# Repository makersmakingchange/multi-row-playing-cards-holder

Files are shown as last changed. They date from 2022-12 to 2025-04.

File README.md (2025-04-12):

<!---  Open Source Assistive Technology: GitHub Readme Template  --->
<!---  TITLE Should match the name of the GitHub repository. Choose something descriptive rather than whimsical.   --->
 # Multi Row Playing Cards Holder

<!---  SUMMARY A brief summary of the project. What it does, who it is for, how much it costs.  --->
The Multi Row Playing Cards Holder is an assistive device for holding playing cards. This fully 3D-printed device aims to assist those with limited hand dexterity by giving them an alternate means of holding their playing cards. Users will be able to place their cards into the tabletop holder which will discreetly display their cards during gameplay.

This design was created by [Dave Jones](https://www.thingiverse.com/djones1t/designs) and posted on [Printables.com](https://www.thingiverse.com/thing:2863434).

<!---  PHOTO  --->
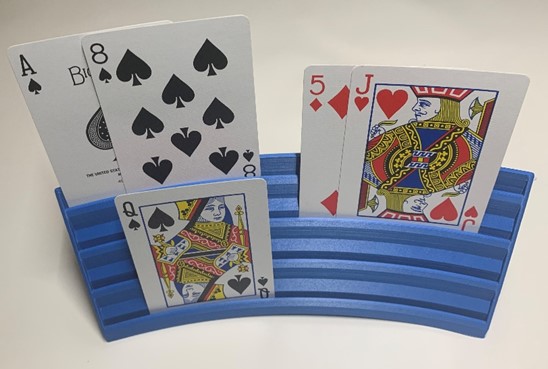
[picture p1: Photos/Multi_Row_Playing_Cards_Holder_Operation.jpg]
A blue 3D printed multi row playing cards holder displaying various cards.


## Makers Making Change Assistive Device Library
 - https://www.makersmakingchange.com/s/product/multi-row-playing-cards-holder/01tJR000000690mYAA

## How to Obtain a Multi Row Playing Cards Holder
### 1. Do it Yourself (DIY) or Do it Together (DIT)

This is an open-source assistive technology, so anyone is free to build it. All of the files and instructions required to build the Multi Row Playing Cards Holder are contained within this repository. Refer to the Maker Checklist below.

### 2. Request a build of this device

If you would like to obtain a Multi Row Playing Cards Holder , you may submit a build request through the [MMC Library Page](https://makersmakingchange.com/project/multi-row-playing-cards-holder/). The requestor is responsible for the cost of materials and any shipping.

### 3. How to build this device for someone else

If you have the skills and equipment to build this device, and would like to donate your time to create the switch for someone who needs it, visit the [MMC Maker Wanted](https://makersmakingchange.com/maker-wanted/) section.

## Getting Started

### 1. Read the Makers Checklist

The Makers Checklist contains a list of tasks to complete to build the device.

### 2. Print the 3D Printable component

The print files can be in the [/Build_Files/3D_Printing_Files](/Build_Files/3D_Printing_Files/) folder.

## Files
<!--- FILES This section includes all the information and files required to build and modify the device, including documentation, design files, and build files. --->

### Documentation
<!--- DOCUMENTATION --->
| Document | Version | Link |
|---|---|---|
| Design Rationale | 1.0 | [Multi_Row_Playing_Cards_Holder_Design_Rationale](/Documentation/Multi_Row_Playing_Cards_Holder_Design_Rationale.pdf) |
| Maker Checklist | 1.0 | [Multi_Row_Playing_Cards_Holder_Maker_Checklist](/Documentation/Multi_Row_Playing_Cards_Holder_Maker_Checklist.pdf) |
| Bill of Materials | 1.0 | [Multi_Row_Playing_Cards_Holder_BOM](/Documentation/Multi_Row_Playing_Cards_Holder_BOM.xlsx) |
| 3D Printing Guide | 1.0 | [Multi_Row_Playing_Cards_3D_Printing_Guide](/Documentation/Multi_Row_Playing_Cards_Holder_3D_Printing_Guide.pdf) |
| Assembly Guide | n/a | No Assembly Required |
| User Guide | 1.0 | [Multi_Row_Playing_Cards_Holder_User_Guide](/Documentation/Multi_Row_Playing_Cards_Holder_User_Guide.pdf) |
| Changelog | 1.0 | [Multi_Row_Playing_Cards_Holder_Changelog](/Documentation/Multi_Row_Playing_Cards_Holder_Changelog.pdf) |

### Design Files
<!-- DESIGN FILES -->
<!-- If possible, include a copy of original design files to facilitate easy editing and customization. --->
 - Not available.

### Build Files
<!-- BUILD FILES -->
 - [3D Printing Files](/Build_Files/3D_Printing_Files)

## Attribution
<!-- ATTRIBUTION -->
<!-- Include any information related to the development of the design. This may include who identified the initial challenge, who contributed to the design --->
 - Design: [Dave Jones](https://www.thingiverse.com/djones1t/designs)
 - Documentation by Neil Squire / Makers Making Change.

## License
<!--- LICENSE --> 
<!-- Choose an appropriate license. We recommend an open-source hardware compatible license. --->
The design of the [Multi Row Playing Cards Holder](https://www.thingiverse.com/thing:2863434) by Dave Jones is licensed under [Creative Commons (International License) Public Domain](http://creativecommons.org/publicdomain/zero/1.0/).

Accompanying material such as instruction manuals, videos, and other copyrightable works that are useful but not necessary to design, make, test, or prepare the Multi Row Playing Cards Holder are published under a Creative Commons Attribution-ShareAlike 4.0 license <https://creativecommons.org/licenses/by-sa/4.0/> (CC BY-SA 4.0).

----

<!-- ABOUT MMC START -->
## About Makers Making Change
[Makers Making Change Logo](https://www.makersmakingchange.com/)

Makers Making Change is a program of [Neil Squire](https://www.neilsquire.ca/), a Canadian non-profit that uses technology, knowledge, and passion to empower people with disabilities.

Makers Making Change leverages the capacity of community based Makers, Disability Professionals and Volunteers to develop and deliver affordable Open Source Assistive Technologies.

 - Website: [www.MakersMakingChange.com](https://www.makersmakingchange.com/)
 - GitHub: [makersmakingchange](https://github.com/makersmakingchange)
 - Bluesky: [@makersmakingchange.bsky.social](https://bsky.app/profile/makersmakingchange.bsky.social)
 - Instagram: [@makersmakingchange](https://www.instagram.com/makersmakingchange)
 - Facebook: [makersmakechange](https://www.facebook.com/makersmakechange)
 - LinkedIn: [Neil Squire Society](https://www.linkedin.com/company/neil-squire-society/)
 - Thingiverse: [makersmakingchange](https://www.thingiverse.com/makersmakingchange/about)
 - Printables: [MakersMakingChange](https://www.printables.com/@MakersMakingChange)

### Contact Us
For technical questions, to get involved, or to share your experience we encourage you to [visit our website](https://www.makersmakingchange.com/) or [contact us](https://www.makersmakingchange.com/s/contact).
<!-- ABOUT MMC END -->

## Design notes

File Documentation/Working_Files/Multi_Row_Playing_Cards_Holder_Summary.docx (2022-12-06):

# Title

Multi Row Playing Cards Holder

## Subtitle

<Short description>

## Device Specifications

Build Time:

< 1hr

1-4 hr

5-10hr

>10hr

Cost:

$0 - $10

$11 - $25

$26 - $50

$51 - $100

$101 - $250

$250+

Stage:

Skills:

Need:

Disability:

Difficulty:

License:

Usages:

Type:

Designer:

## Device Details

### Overview

The Multi-Row Playing Cards Holder is an assistive device for holding playing cards. This fully 3D-printed device aims to assist those with limited hand dexterity by giving them an alternate means of holding their playing cards. Users will be able to place their cards into the tabletop holder which will discreetly display their cards during gameplay.

Original device listing on printables.com: Thing files for Full Size Playing Card Holder by Djones1t – Thingiverse (https://www.thingiverse.com/thing:2863434/files)

### Usage

This device is intended to be used with standard sized playing cards. Larger cards can be used but will decrease the maximum number of cards that can be held. Cards can be placed among its four rows to be displayed.

### Cost

Approximately $1.60 CAD for filament.

### Build Instructions

The Multi Row Playing Cards Holder consists of a single 3D printed component. Refer to the Maker Guide and 3D Print guide for detailed instructions.

#### Skills Required

- 3D Printing

#### Time Required

- 3D Printing Time: 10h 26m
- Assembly Time: None

### 3D Printing

- 1X Multi-Row Playing Cards Holder

### Attribution

Design: Dave Jones (https://www.thingiverse.com/djones1t/designs) licensed under Creative Commons (International License) Public Domain (https://creativecommons.org/licenses/by/4.0/).

Documentation: Neil Squire / Makers Making Change

© 2022 by Neil Squire. This work is licensed under the CC BY SA 4.0 License: http://creativecommons.org/licenses/by-sa/4.0 Files available at https://makersmakingchange.com/project/playing-cards-holder Page 1 of 2

V1.0 | November 2022 Playing Cards Holder Summary

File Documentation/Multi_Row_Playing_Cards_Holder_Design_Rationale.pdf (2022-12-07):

V1.0 | October 2022

## Playing Cards Holder

## DESIGN RATIONALE

© 2022 by Neil Squire. (https://neilsquire.ca/)

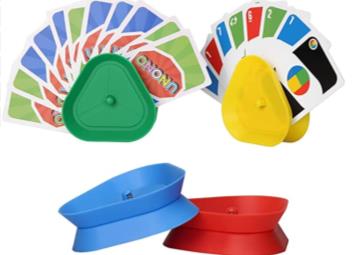
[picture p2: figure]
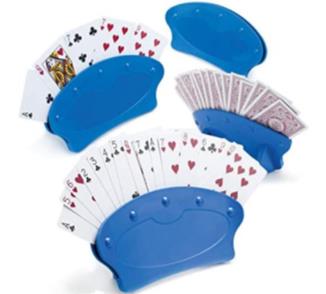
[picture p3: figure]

This work is licensed under the CC BY SA 4.0 License: http://creativecommons.org/licenses/by-sa/4.0
Files available at https://makersmakingchange.com/project/multi-row-playing-cards-holder | Page 1 of 7

### Introduction

The Playing Cards Holder is an assistive device for holding playing cards. This fully 3D printed device aims to assist those with limited dexterity by giving them an alternate means for holding their playing cards. Users will be able to place their cards into the holder to have them displayed during game play.

### Research

### Handheld Holders

There are a variety of commercially available card holders that assist in holding cards within a person’s hand. This type sandwiches cards between its two halves and holds them secure with friction. They cost approximately $20 and are targeted to aid users with arthritis.

Brybelly Triangle Shaped Hands-Free Playing Card Holder : Amazon.ca: Toys & Games (https://www.amazon.ca/Brybelly-Triangle-Shaped-Hands-Free-Playing/dp/B00DQRDK6K?hvadid=80470598951881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)

### Tabletop Holders

The other common type is the tabletop holder. This allows cards to be held hands free but requires a table or surface to be placed on. They cost around $25 for a set and are targeted to aid users with arthritis.

Playing Card Holder Tray Great for Seniors & Kids Hands Free Playing Card Holders (Set of 4), Standard Playing Card Decks - Amazon Canada (https://www.amazon.ca/Playing-Holder-Great-Seniors-Holders/dp/B07BHRRJ9K?hvadid=80470598951881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)

## DESIGN RATIONALE

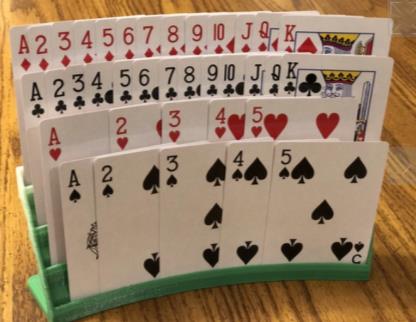
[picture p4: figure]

Files available at https://makersmakingchange.com/project/multi-row-playing-cards-holder | Page 2 of 7

### Requirements

### Goals

G01 | Make it easier for users with limited dexterity hold playing cards
G02 | Assist recreation and leisure

### Functional Requirements

F01 | Cards should be kept hidden from other players
F02 | Cards should still be accessible when holder is full
F03 | Holder must be stable enough to not tip over
F04 | Must be easy to place and take cards from holder
| (How many cards should it hold?)

### Non-functional Requirement

NF01 | Should be easy to clean
NF02 | Capable of holding various sized cards

### Constraints

C01 Must be printable on standard sized 3D printers

### Existing Designs

Feedback was gathered from users with various degrees of hand dexterity challenges.

### Multi-Tier Card Holder - User Test 1

This design allows for four rows of cards to be held with a slight curve. This offers enough room to hold an entire standard deck of cards: one full suit (13) per row. However, it did not encompass the required user accessibility. Users found it too difficult to access and place cards among the multiple crowded rows. Singles tiered card holders will be the ideal approach.

Source: Full Size Playing Card Holder by Djones1t - Thingiverse (https://www.thingiverse.com/thing:2863434)

## DESIGN RATIONALE

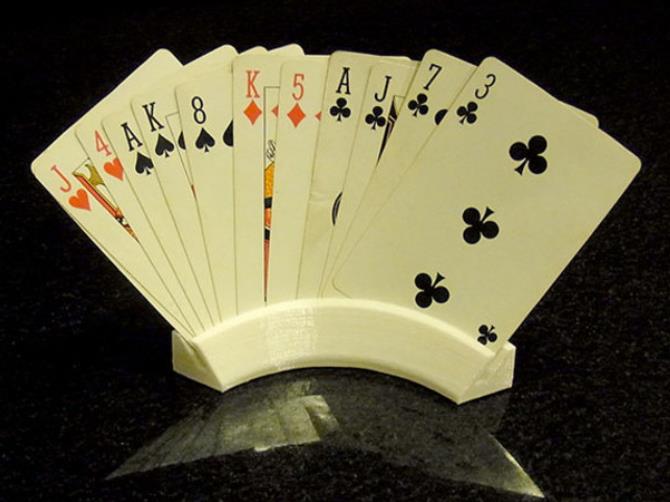
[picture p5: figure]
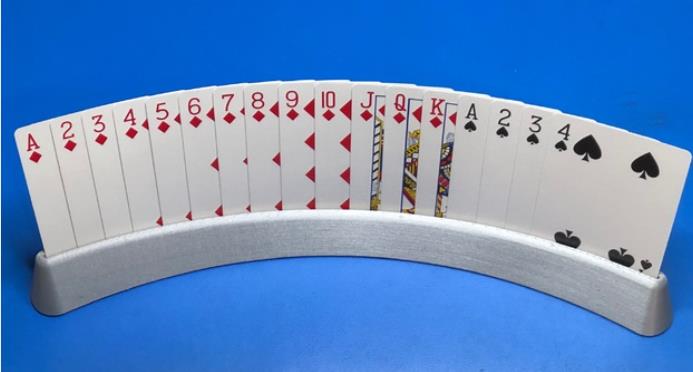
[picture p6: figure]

Files available at https://makersmakingchange.com/project/multi-row-playing-cards-holder | Page 3 of 7

Licence: Creative Commons — Attribution 4.0 International — CC BY 4.0 (https://creativecommons.org/licenses/by/4.0/legalcode)

### Single Tier Card Holder - User Test 2

This single layer card holder curves to angle the cards towards the users and holds the cards in a tilted back position. After testing, users found the single layer to be ideal for their accessible needs but found this design too small. The holder became too crowded when loaded up with cards.

Source: Playing Card Holder - Holds your cards for you while you play! by muzz64 - Thingiverse (https://www.thingiverse.com/thing:781900)

Licence: Creative Commons — Attribution 4.0 International — CC BY 4.0 (https://creativecommons.org/licenses/by/4.0/legalcode)

### Other Design Considerations

### Holder 1 – Extra Wide Playing Card Holder

- Designed to be the maximum size for the Prusa MK3
- Must be scaled to 85% to fit on Ender3 bed
- Functionality decreased due to scaling: card slot quite narrow
- 5h 36m print time
- Single tier
- Curved slightly towards user
- Holds cards slightly tilted back
- Holds 4 non-over lapping cards and approximately a maximum of 18 spaced closely

## DESIGN RATIONALE

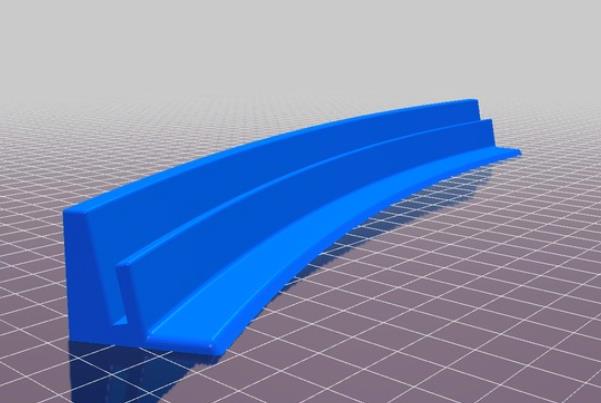
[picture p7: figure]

Files available at https://makersmakingchange.com/project/multi-row-playing-cards-holder | Page 4 of 7

Source: Thing files for Extra Wide Playing Card Holder by abelsm2 - Thingiverse (https://www.thingiverse.com/thing:3417179/files)

Licence: Creative Commons (https://creativecommons.org/licenses/by-nc-sa/4.0/legalcode)

### Holder 2 – Playing Card Holder

- Must be scaled to 90% to fit on Ender3 bed
- Functionally still works great while scaled
- 5h 41m print time
- Single tier
- Curved slightly towards user
- Holds cards slightly tilted back
- Wider base for stability
- Holds 4 non-over lapping cards and approximately a maximum of 20 spaced closely
- Interesting design with the rear wall being taller than the from allowing cards to be ‘banked’ in

Notes: This would be a good design to get user feedback on. It has the highest card capacity of the single tier holders considered. Its wide base makes it very stable and almost hard to tip over. It would also be interesting to see if users find this cross section more accessible.

Source: Thing files for Playing Card Holder by skartz - Thingiverse (https://www.thingiverse.com/thing:2745725/files)
Licence: Creative Commons (https://creativecommons.org/licenses/by-nc-sa/4.0/legalcode)

### Holder 3 – Playing Cards Holder

- Sized perfectly for Prusa Mini (will fit on all maker printers)
- 4h 17m print time
- Single tier
- Slight curve
- Holds cards straight up (no lean)
- Circular feet for stability
- Holds 3 non-over lapping cards and approximately a maximum of 14 spaced closely

## DESIGN RATIONALE

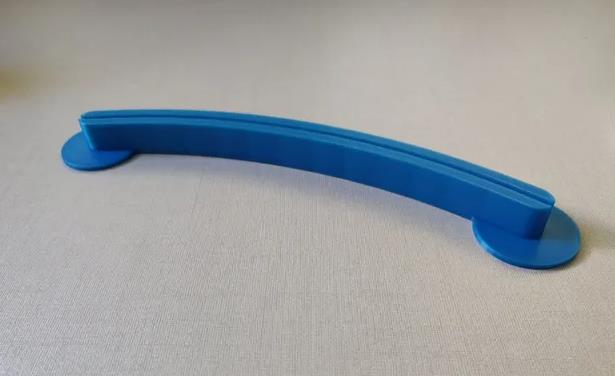
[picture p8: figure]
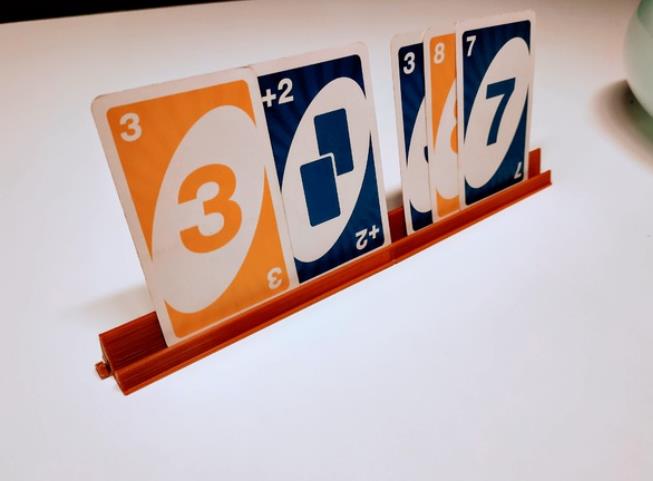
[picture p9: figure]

Files available at https://makersmakingchange.com/project/multi-row-playing-cards-holder | Page 5 of 7

Notes: User feedback on this design could be beneficial. Its print size is convenient for maker printers and the design of its base makes it very stable. More information on whether this meets user accessibility would be needed.

Source: Playing Cards Holder by DrorFux | Download free STL model | Printables.com (https://www.printables.com/model/175640-playing-cards-holder)
Licence: Creative Commons (https://creativecommons.org/licenses/by-nc-sa/4.0/legalcode)

### Holder 4 – Connectable Playing Cards Holder

- Modular design allowing for multiple units to connect together
- Individual components will fit on any printer
- 1h 48m print time
- No curve
- Holds cards slightly tilted back
- Similar cross section as holder 2
- Smaller size: 12cm long and 2 cm wide
- Tab to attach multiple together is quite weak

Notes: Due to its narrow base and lack of curve, this design was quite unstable. However, it was the only modular single tier card holder I could find. If a custom holder is to be designed, this could be a good foundation to expand from.

Source: Thing files for Card holder for playing cards by elliotsfar - Thingiverse (https://www.thingiverse.com/thing:4248953/files)

## DESIGN RATIONALE

Files available at https://makersmakingchange.com/project/multi-row-playing-cards-holder | Page 6 of 7

Licence: Creative Commons (https://creativecommons.org/licenses/by-nc-sa/4.0/legalcode)

### Existing Design Comparison

| Design 1 | Design 2 | Design 3 | Design 4 | User Test 1
Style (handheld / desk) | Desk | Desk | Desk | Desk | Desk
Size [cm] | ~27 x 2.2 x 2 | ~25 x 2.2 x 2.7 | ~21 x 1.7 x 1.1 | ~12 x 1.6 x 2 | ~20.5 x 7.5 x 4
Print Time | 5h 36m | 5h 41m | 4h 17m | 1h 48m | 10h 26m
Cost | ~$1.00 | ~$1.05 | ~$0.85 | ~$0.33 | 64g
License | Creative Commons | Creative Commons | Creative Commons | Creative Commons | Creative Commons (https://creativecommons.org/licenses/by-nc-sa/4.0/legalcode)

### User Feedback

Holder 1, Holder 2, and the User test 1 card holders were sent for user feedback. The following are some of their responses.

### What challenges will this device help overcome?

- Arthritis, limited dexterity, etc. post CVA, brain injury, cognitive decline, chronic pain, fine and gross motor limitations, decreased strength/endurance, arthritis, post surgery (shoulder, wrist, etc.), paralysis, MS, Guillain Barre Syndrome, CP, ALS, Parkinson’s/tremors,

### How will this device be used?

- Handheld? A fan shape would be better for handheld
- At a desk or a table? Yes
- Used with one hand? One or two, depending on the person

### What style of holder works best?

- Multiple rows? Depending on game, multiple row would be best. Better to have too much room rather than not enough.
- Single row?

How many cards should this holder hold? Games like bridge deal 13 cards, cribbage deals 6 cards

## DESIGN RATIONALE

Files available at https://makersmakingchange.com/project/multi-row-playing-cards-holder | Page 7 of 7

### Additional Comments

- Is there an handheld option? It should be thicker to hold onto or have an option to attach to a tray on a wheelchair perhaps or have a hand strap.
- could suction cups or something similar be added to the table top version so that it doesn’t slide around when clients are removing a card?

### Detailed Design

After receiving user feedback, the optimal design for the paying cards holder is either User Test 1 or Holder 2. The first is a multi-tier holder capable of holding many cards. It has approximate dimensions of 20.5 x 7.5 x 4 cm. The initial impression of this holder was that it may become too difficult to use once full of cards. However, after further testing from users, the fact that it can hold over twice the number of cards makes it a better option when used below max capacity.

The second holder is the largest single tier holder considered but may still be limiting based on the maximum number of cards it can hold. It has approximate dimensions of 25 x 2.2 x 2.7 cm. This is a good option based on its wide base and cross section design.

Both designs are maker friendly, sturdy, and accessible. Therefore, both designs will be released as separate devices.

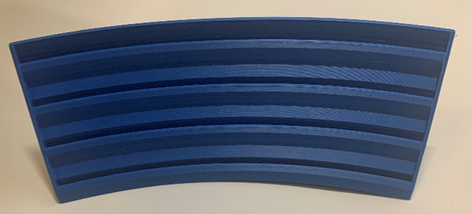
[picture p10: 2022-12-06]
Photos/Multi Row Playing Cards Holder Front.png

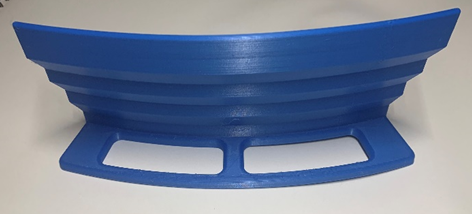
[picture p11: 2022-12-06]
Photos/Multi Row Playing Cards Holder Back.png

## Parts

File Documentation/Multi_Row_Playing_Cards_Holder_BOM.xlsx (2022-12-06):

Device: Multi Row Playing Cards Holder |  | Total Cost | Total Print time (hr) | Total filament (g)
Version: V1.0 | Date Created: 11/23/2022 | $1.60 | 10.43 | 64
Commercial Parts:
Part type (Electrical. Mechanical, Sanitization, ect) | Part Name | Quantity Needed | Pkg Quantity | Price per package | Price per Unit | Price for qty needed | Link
No commercial parts needed
3D Printed Parts ESTIMATED PRICING USING 1KG ROLL COST: | $25.00
Part | Description | Quantity Needed | TOTAL Mass (g) | Estimated Price | Print Time (Min) | Link
Full Sized Playing Cards Holder | Multi-Tier Holder | 1 | 64 | $1.60 | 626 | Thing files for Full Size Playing Card Holder by Djones1t - Thingiverse (https://www.thingiverse.com/thing:2863434/files)
 |  |  |  | $0.00
 |  |  |  | $0.00
 |  |  |  | $0.00
 |  |  |  | $0.00
 |  |  | Total Print Cost: | $1.60
Tools for Assembly
No tools needed
Alternatives (if there are other sources for some parts link them below)
Part and description

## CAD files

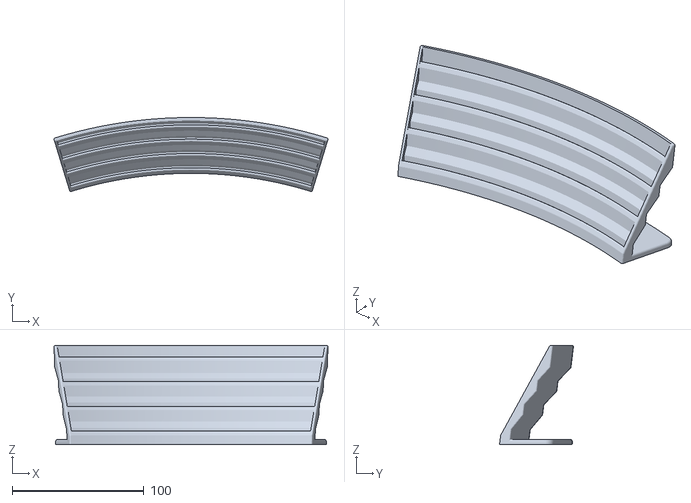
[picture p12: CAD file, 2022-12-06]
Build_Files/3D_Printing_Files/holder-4row.stl
208.2 x 56.2 x 75.5

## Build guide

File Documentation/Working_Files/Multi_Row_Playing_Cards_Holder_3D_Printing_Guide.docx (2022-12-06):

# 3D Printing Summary

Metrics | 4 Row Playing Cards Holder
Total Print Time (min) | 626
Total Number of Components | 1
Typical Total Mass (g) | 64
Typical Number of Print Setups | 1

# 3D Printing Settings

Print File Name | Qty | Total Print Time (hr:min) | Mass (g) | Infill (%) | Support(Y/N) | Layer Height/ Nozzle Diameter(mm) | Notes (orientation, special settings, etc.)
Holder-4row.stl | 1 | 10:26 | 30 | 15 | N | 0.2/0.4 | -Rotate to fit on print bed -Do not scale

# Customization Options

Users may request their choice of print colour.

# Post-Processing

No post-processing is required as this part does not require any supports. Rather inspect the print to ensure that all edges and surfaces are smooth.

# Examples of Quality Prints

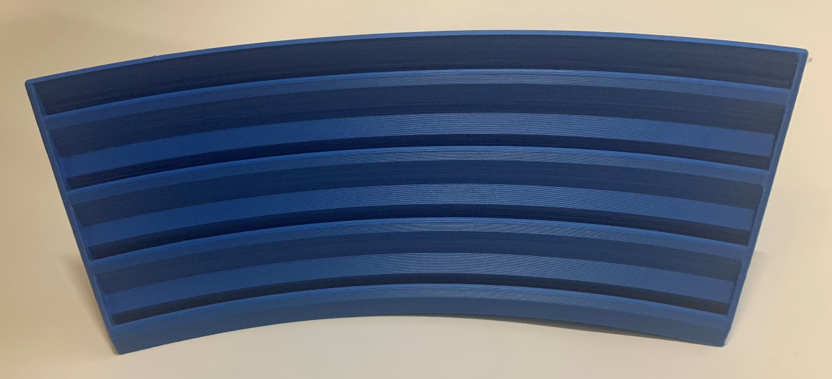
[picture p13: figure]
A blue 3D printed playing cards holder with 4 rows to hold cards.

© 2022 by Neil Squire. This work is licensed under the CC BY SA 4.0 License: http://creativecommons.org/licenses/by-sa/4.0 Files available at https://makersmakingchange.com/project/multi-row-playing-cards-holder Page 1 of 2

V1.0 | November 2022 Multi Row Playing Cards Holder 3D Printing Guide

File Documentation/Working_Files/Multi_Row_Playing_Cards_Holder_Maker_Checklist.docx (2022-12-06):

# Maker To Do List

- Read through the Print Guide to become familiar with print orientation and settings
- Talk to User about customization options (e.g., colour)
- Print the device
- Test the device
- Print “User Quick Guide”

# Items to Give to User

- Multi Row Playing Cards Holder
- “User Quick Guide”

© 2022 by Neil Squire. This work is licensed under the CC BY SA 4.0 License: http://creativecommons.org/licenses/by-sa/4.0 Files available at https://makersmakingchange.com/project/multi-row-playing-cards-holder Page 1 of 1

V1.0 | November 2022 Multi Row Playing Cards Holder Maker Checklist

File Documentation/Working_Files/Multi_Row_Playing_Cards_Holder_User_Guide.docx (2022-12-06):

## Introduction

The Multi Row Playing Cards Holder is an assistive device for holding playing cards. This fully 3D-printed device aims to assist those with limited hand dexterity by giving them an alternate means of holding their playing cards. Users can place their cards into the tabletop holder which will discreetly display their cards during gameplay.

## Features

This device has 4 rows of slots for holding playing card and on the back side is a handle to carry it from.

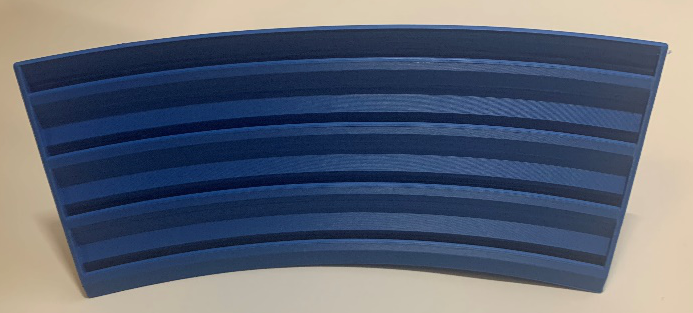
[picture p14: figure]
The front side of a blue 3D printed playing cards holder with 4 rows to display cards.
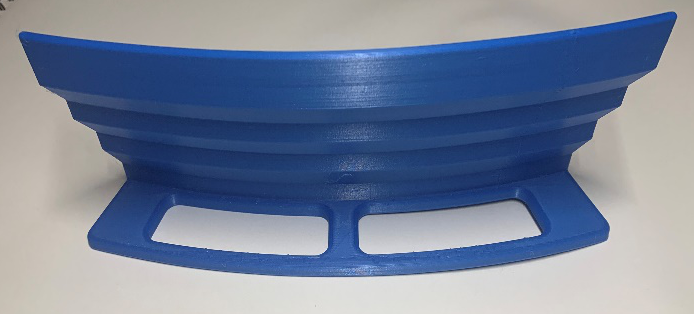
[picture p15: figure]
The back side of a blue 3D printed playing cards holder showing that the base also acts as a handle to carry it from.

## Usage

Place the Playing Cards Holder on a flat surface and face it away from other players. Cards can then be place among the four rows to be displayed during game play.

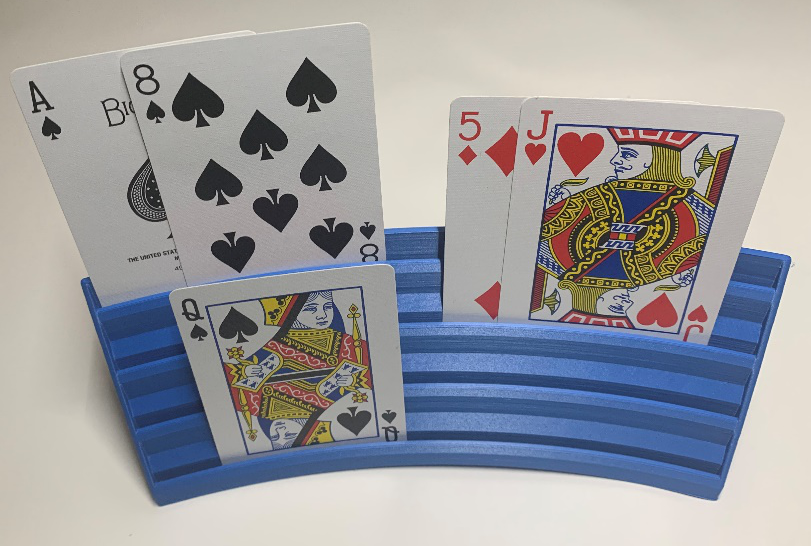
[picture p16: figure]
A blue 3D printed playing cards holder displaying various cards.

## Compatibility

This cards holder is intended to be used with standard sized playing cards. Larger cards can be used but will decrease the maximum number of cards that can be displayed.

## Specifications

Dimensions (mm) | | | | | | Mass (g)
Height | Base Width | Card Slot Length | Card Slot Width | Handle Length | Handle Width
75 | 40 | 200 | 2 | 150 | 23 | 64

## Cleaning

The Playing Cards Holder can be wiped down with sanitizing cleaners or gently scrubbed with a soft-bristled brush and mild soapy water. Do not subject the device to high heat as this may damage the 3D-printed material.

© 2022 by Neil Squire. This work is licensed under the CC BY SA 4.0 License: http://creativecommons.org/licenses/by-sa/4.0 Files available at https://makersmakingchange.com/project/multi-row-playing-cards-holder Page 2 of 3

V1.0 | November 2022 Multi Row Playing Cards Holder user Quick Guide

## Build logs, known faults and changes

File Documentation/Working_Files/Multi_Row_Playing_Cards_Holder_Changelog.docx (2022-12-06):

# Version 1.0 | 2022/November/21 | 4 Row Cards Holder

- Initial design by Dave Jones (https://www.thingiverse.com/djones1t/designs) is licensed under Creative Commons (International License) Public Domain (https://creativecommons.org/licenses/by/4.0/).
- Multi-tier cards holder
- Documentation by Neil Squire / Makers Making Change

© 2022 by Neil Squire. This work is licensed under the CC BY SA 4.0 License: http://creativecommons.org/licenses/by-sa/4.0 Files available at https://makersmakingchange.com/project/multi-row-playing-cards-holder Page 1 of 1

V1.0 | November 2022 Multi Row Playing Cards Holder changelog
